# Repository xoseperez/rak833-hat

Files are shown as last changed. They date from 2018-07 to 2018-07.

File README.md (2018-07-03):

# RAK833 Hat for Raspberry Pi

This repository contains the PCB design for a hat and installation procedure to use a RAK833 MiniPCI-E module with a Raspberry Pi.




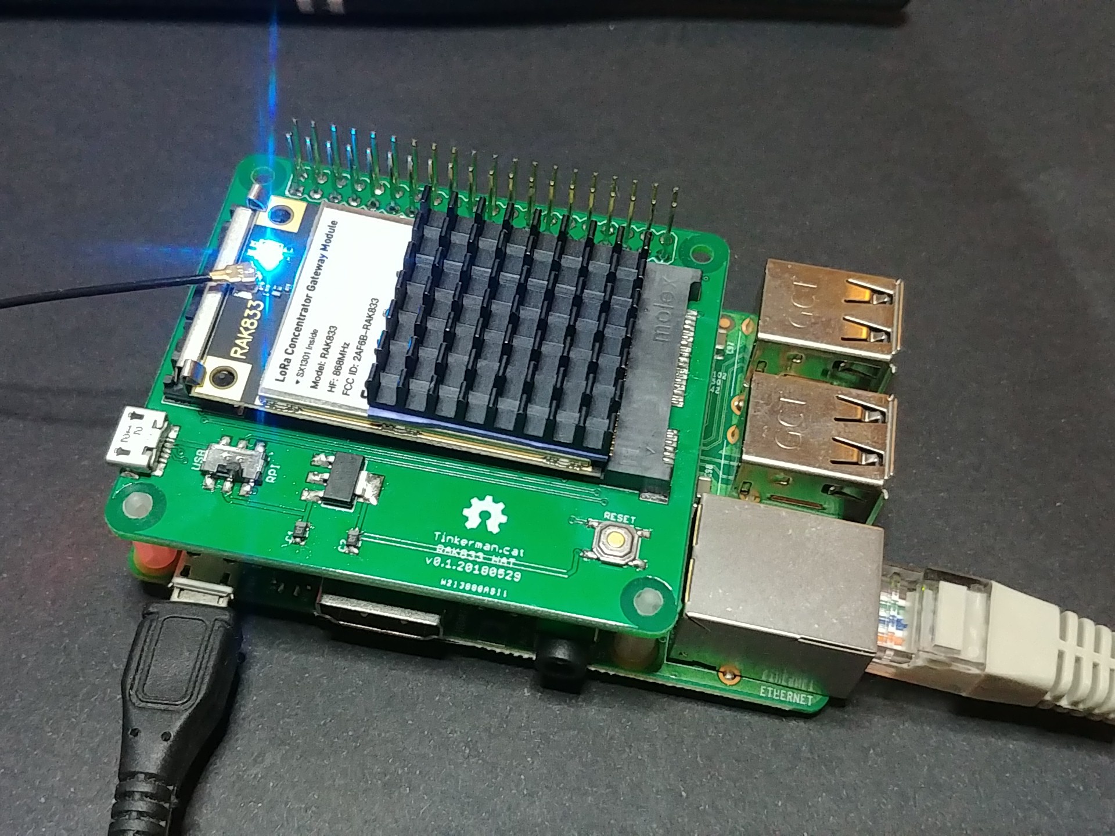
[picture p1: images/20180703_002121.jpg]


## Licenses

The installation procedure is based on the [ttn-zh](http://github.com/ttn-zh) installation procedure for the [IMST iC880a](https://github.com/ttn-zh/ic880a-gateway) module and thus uses the same GPL-3.0 license.

The PCB design and layout is licensed under CC-SA-BY-4.0 International.

License files are available under each folder.

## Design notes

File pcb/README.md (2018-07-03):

# RAK833 Hat

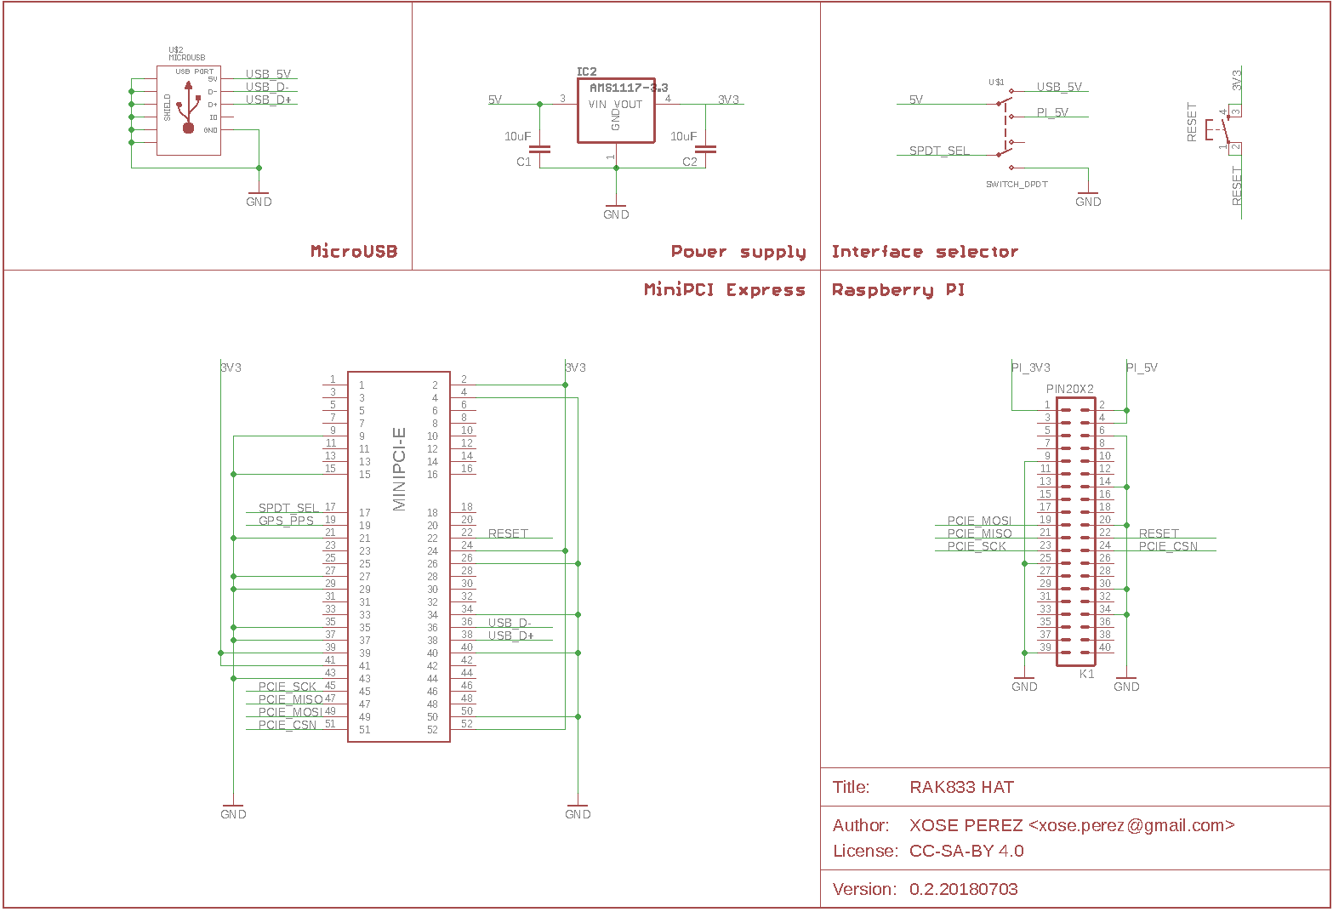
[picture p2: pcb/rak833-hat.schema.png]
Schematic


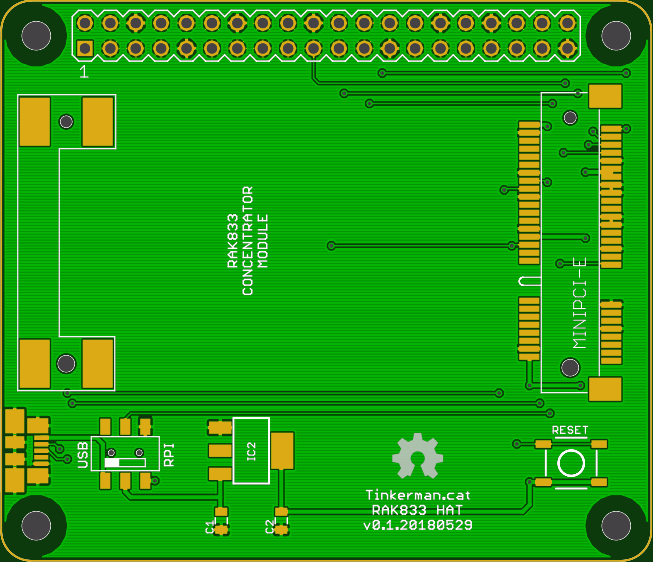
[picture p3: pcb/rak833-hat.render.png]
Render


## Bill of materials

This is the bill of materials for the RAK833 Hat for Raspberry Pi.

You will need an SPI or SPI/USB (more expensive) RAK833 concentrator. RAK Wireless sells them on their Aliexpress store, there is no other place to buy it from IFAIK.

|Item|Qty|Datasheet|Reference|Unit price (*)|
| :--- | :---: | :---: | :---: | :---: |
| RAK833 PCB (lead-free, buying 5 units) | 1 | | [PCBWay](https://www.pcbway.com/project/shareproject/RAK833_Raspberry_Pi_Hat_v0_1_20180529.html) | 3.8€ |
| RAK833 MiniPCI | 1 | [PDF](http://docs.rakwireless.com/en/RAK833%20PCIE%20LoRa%20Gateway/hardware%20design/RAK833%20LoRa%20Gateway%20DataSheet%20V1.3.pdf) | [Aliexpress (SPI-only)](https://www.aliexpress.com/item/RAK833-SPI-SX1301Chip-868-915MHz-Industrial-Grade-Mini-PCIe-LoRa-Gateway-Concentrator-Module-support-SPI-Interface/32887664396.html)<br />[Aliexpress (SPI & USB)](https://www.aliexpress.com/item/RAK833-SPI-USB-Industrial-Grade-Mini-PCIe-LoRa-Gateway-Concentrator-Module-SX1301-FT2232H-Chip-868-915MHz/32867370031.html) | 86.41€<br />103.87€ |
| Glass Fiber Antenna Gain 6dbm | 1 | | [Aliexpress](https://www.aliexpress.com/store/product/Glass-Fiber-Antenna-Gain-6dbm-Transmission-range-is-further-LoRa-Gateway-Antenna-with-433-470-868/2805180_32852314761.html) | 24.02€ |
| Molex MiniPCI-E 4.0H connector | 1 | [PDF](https://www.mouser.es/datasheet/2/276/480996701_sd-155861.pdf) | [Mouser (connector)](https://www.mouser.es/ProductDetail/538-67910-1002) <br /> [Mouser (latch)](https://www.mouser.es/ProductDetail/538-48099-5701) | 1.82€<br />1.07€ |
| Molex 47346-1001 microUSB connector | 1 | [PDF](https://www.mouser.es/datasheet/2/276/0473461001_IO_CONNECTORS-272892.pdf) | [Mouser](https://www.mouser.es/ProductDetail/538-47346-1001) | 0.55€ |
| AMS1117-3V3 | 1 | | [Aliexpress](https://www.aliexpress.com/item/10pcs-AMS1117-3-3-AMS1117-LM1117-1117-3-3V-1A-Voltage-Regulator/32348815272.html) | 0.03€ |
| 10uF 6.3V Tantalum Capacitors | 2 | [PDF](https://www.mouser.es/datasheet/2/40/tps-776850.pdf) | [Mouser](https://www.mouser.es/ProductDetail/581-TPSR106K006R1500) | 0.60€ |
| SMD DPDT switch | 1 | | [Aliexpress](https://www.aliexpress.com/item/5PCS-3-Position-6-Pins-DPDT-Panel-PCB-Mount-Mini-SMD-SMT-Slide-Switch-7x6x4mm/32553945435.html) | 0.69€ |
| SMD push button | 1 | | [Aliexpress](https://www.aliexpress.com/item/100PC-Lot-SMD-4-4-1-5MM-4X4X1-5MM-Tactile-Tact-Push-Button-Micro-Switch-Momentary/32623940621.html) | 0.01€ |
| Raspberry Pi 3 | 1 | | | ~30€ |
| 20x2 2.54pitch header for Raspberry Pi | 1 | | | ~0.25€ |
| **TOTAL (SPI-only version)** | | | | **~150€** |

(*) Prices are shown here for reference. They might change depending on your supplier. They also change depending on the number of units you buy. All prices excluding shipping or customs.

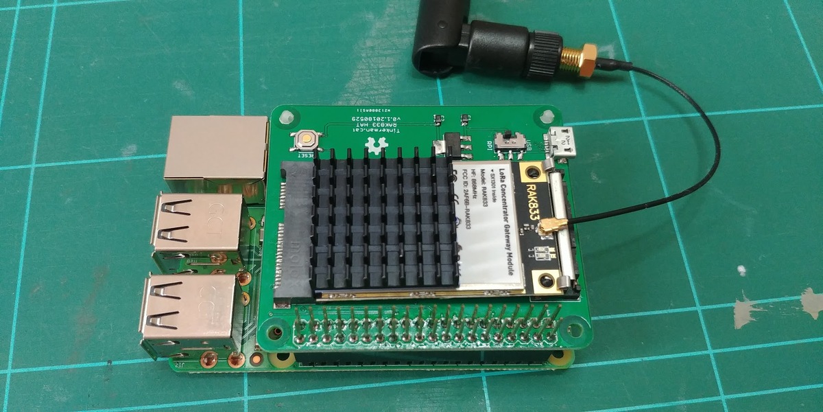
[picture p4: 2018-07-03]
images/small/20180702_132220s.jpg

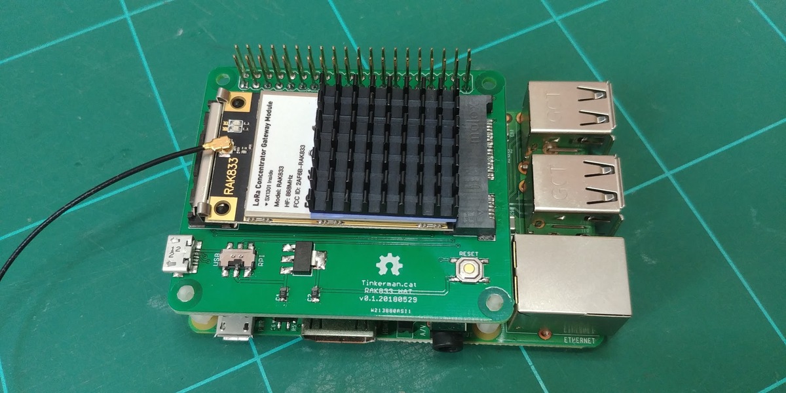
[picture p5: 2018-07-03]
images/small/20180702_132230s.jpg

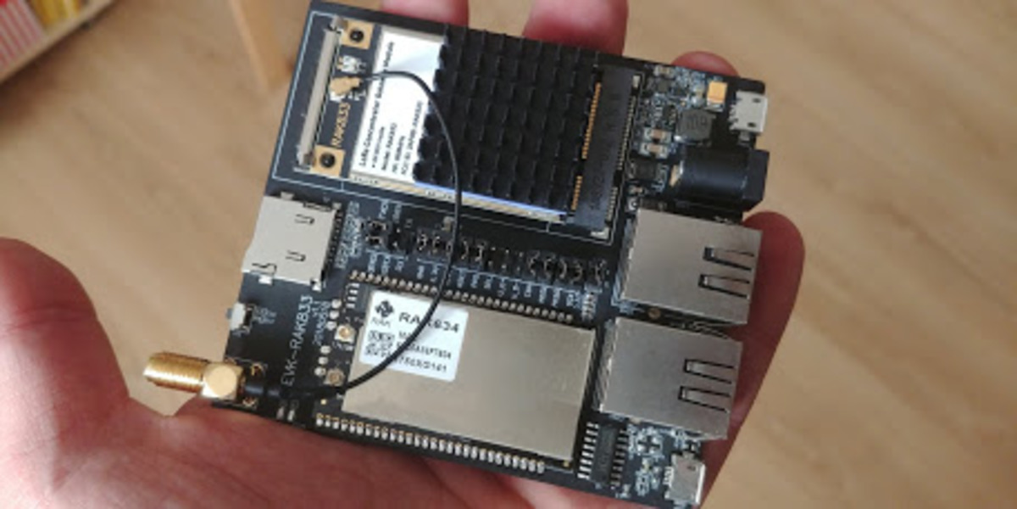
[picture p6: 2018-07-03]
images/small/20180626_130729s.jpg

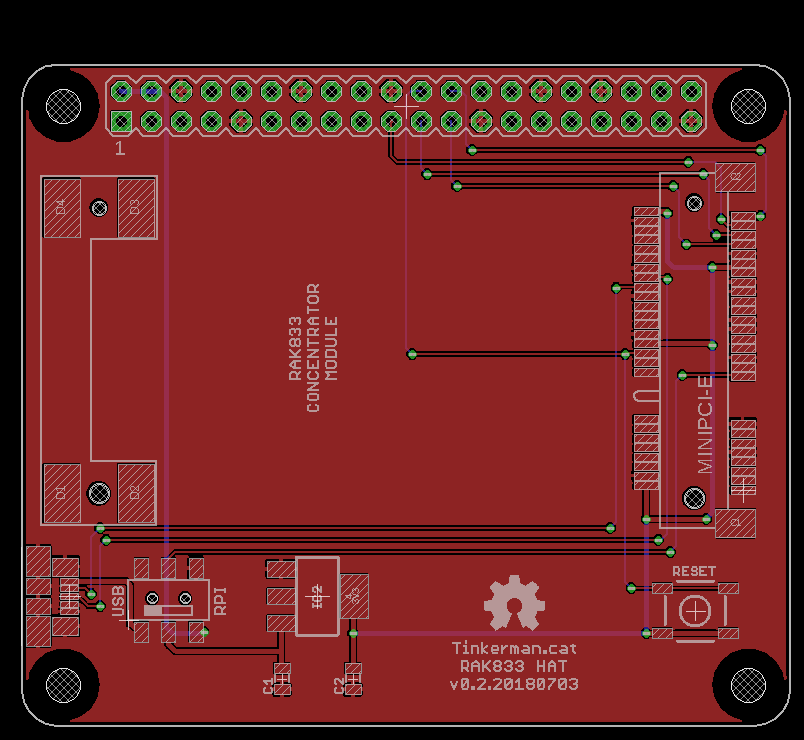
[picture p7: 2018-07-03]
pcb/rak833-hat.layout.png

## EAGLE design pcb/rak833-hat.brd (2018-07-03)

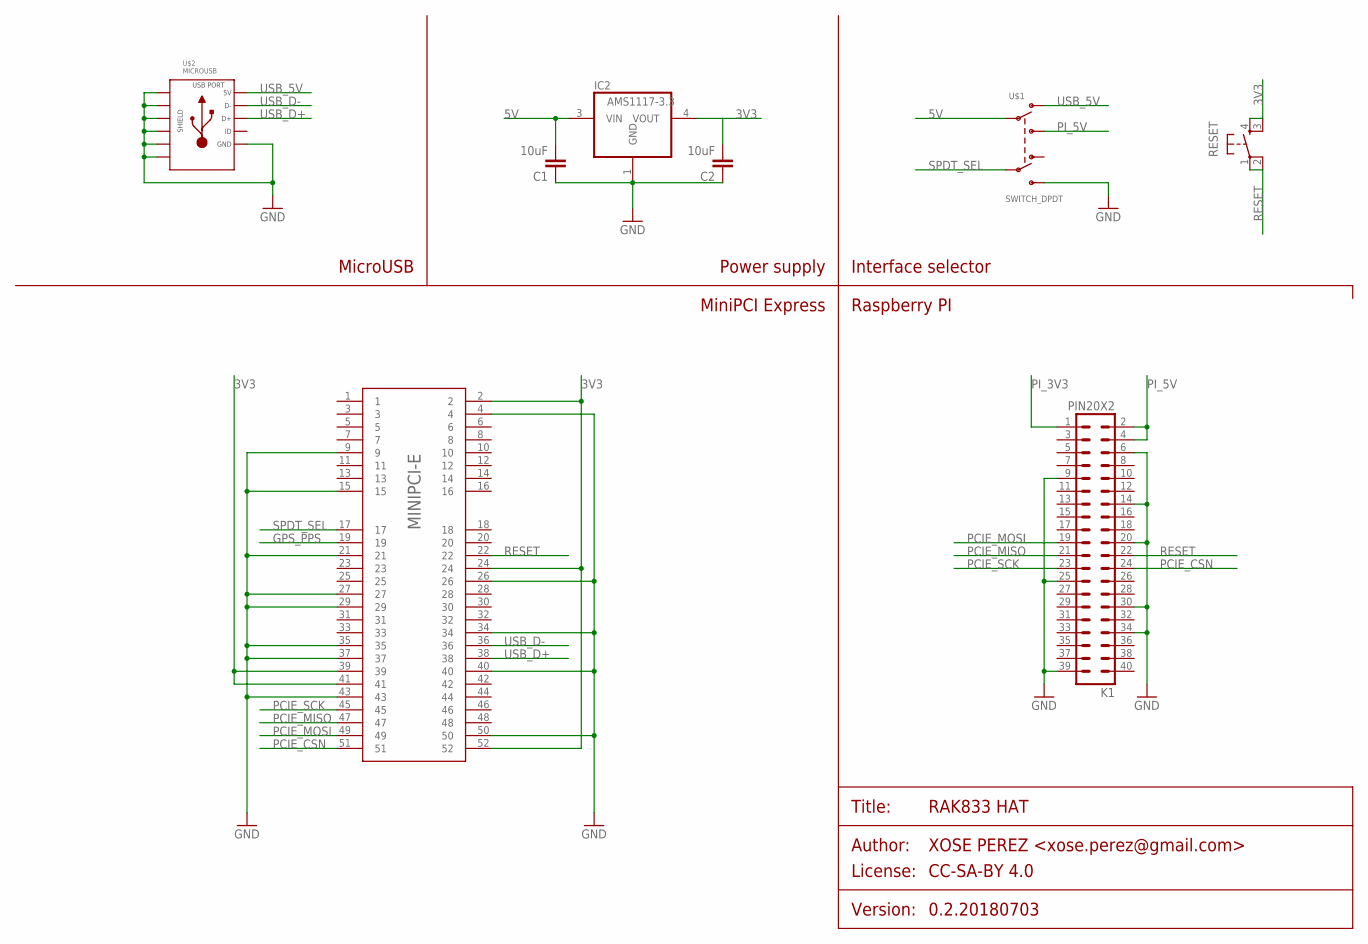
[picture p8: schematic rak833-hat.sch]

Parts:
C1, C2: 10uF; 0805
IC2: AMS1117-3.3; SOT223
K1: PIN20X2; PIN_20X2
MINIPCI-E: MINI-PCIE-RAW; 67910-MINI-PCIE
RESET: TACTILE_BUTTON_SMD; TACTILE-BUTTON-SMD
U$1: SWITCH_DPDT; SWITCH_DPDT_SMD
U$2: MICROUSB; MICROUSB-MOLEX-47346-0001

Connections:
3V3: C2.2, IC2.4 (VOUT), MINIPCI-E.2, MINIPCI-E.24, MINIPCI-E.39, MINIPCI-E.41, MINIPCI-E.52, RESET.3 (SWB2), RESET.4 (SWA2)
5V: C1.2, IC2.3 (VIN), U$1.A1 (P1)
GND: C1.1, C2.1, IC2.1 (GND), K1.6, K1.9, K1.14, K1.20, K1.25, K1.30, K1.34, K1.39, MINIPCI-E.4, MINIPCI-E.9, MINIPCI-E.15, MINIPCI-E.21, MINIPCI-E.26, MINIPCI-E.27, MINIPCI-E.29, MINIPCI-E.34, MINIPCI-E.35, MINIPCI-E.37, MINIPCI-E.40, MINIPCI-E.43, MINIPCI-E.50, U$1.C2 (S2), U$2.GND, U$2.SLD1, U$2.SLD2, U$2.SLD3, U$2.SLD4, U$2.SLD5, U$2.SLD6
GPS_PPS: MINIPCI-E.19
PCIE_CSN: K1.24, MINIPCI-E.51
PCIE_MISO: K1.21, MINIPCI-E.47
PCIE_MOSI: K1.19, MINIPCI-E.49
PCIE_SCK: K1.23, MINIPCI-E.45
PI_3V3: K1.1
PI_5V: K1.2, K1.4, U$1.C1 (S1)
RESET: K1.22, MINIPCI-E.22, RESET.1 (SWA1), RESET.2 (SWB1)
SPDT_SEL: MINIPCI-E.17, U$1.A2 (P2)
USB_5V: U$1.B1 (O1), U$2.VCC (5V)
USB_D+: MINIPCI-E.38, U$2.D+
USB_D-: MINIPCI-E.36, U$2.D-

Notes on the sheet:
MiniPCI Express
Raspberry PI
Interface selector
Power supply
MicroUSB

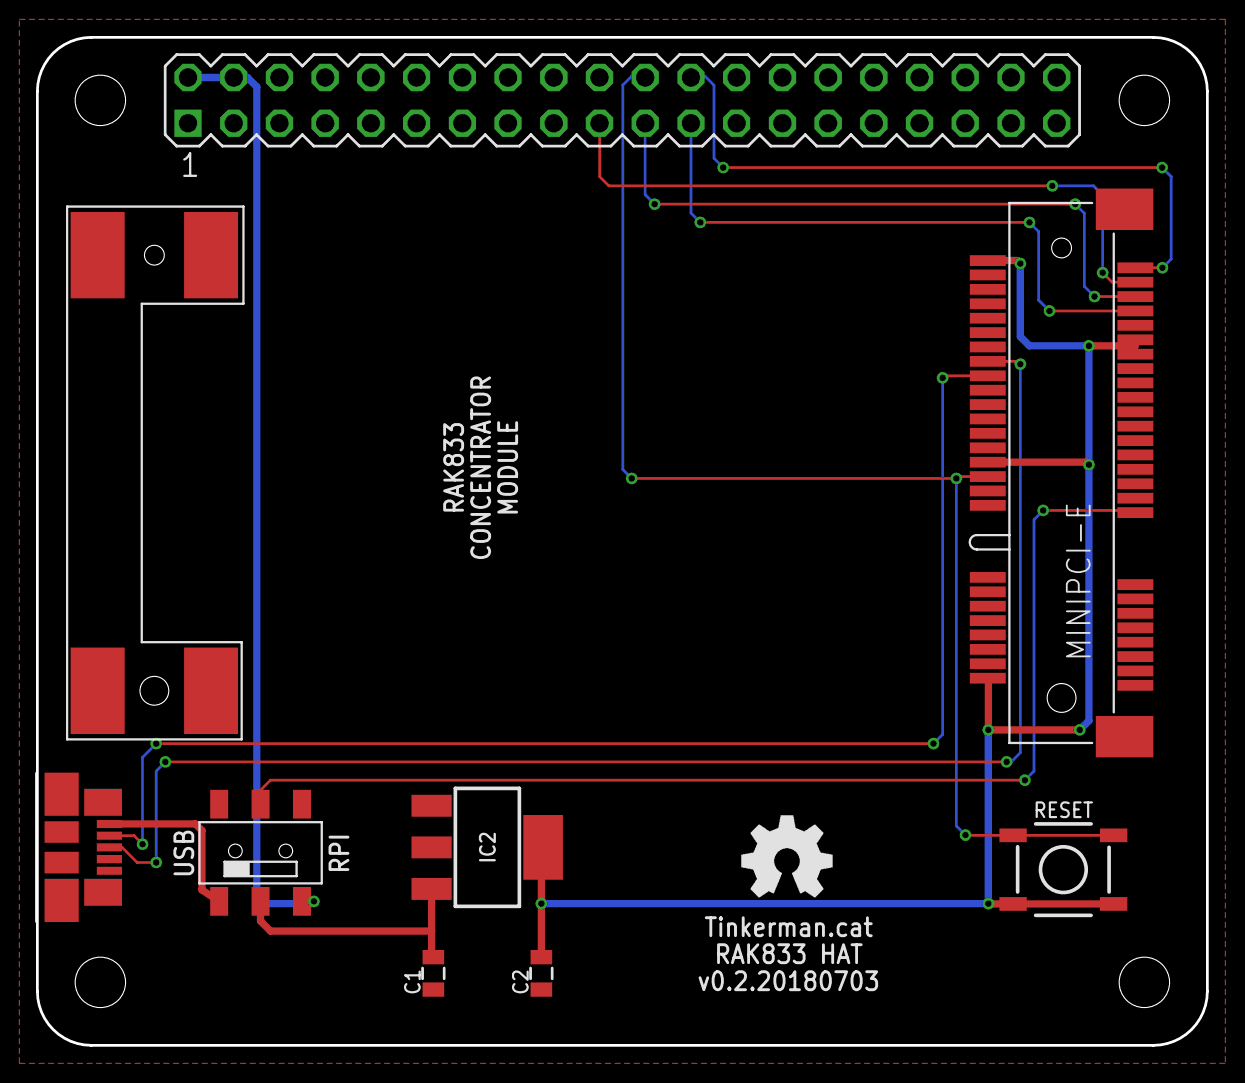
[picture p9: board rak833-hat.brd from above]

Board: 2 copper layers, 65.0 x 56.0 mm, 8 parts (0 on the bottom side), 13 nets.

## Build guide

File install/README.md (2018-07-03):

# The Things Network: RAK833-based gateway

Reference setup for [The Things Network](http://thethingsnetwork.org/) gateways based on the RAK833 USB concentrator with a Raspberry Pi host using the RAK833 hat available in this same repository.

> This documentation and installation procedure is based largely on [gonzalocasas](https://github.com/gonzalocasas) and [ttn-zh](https://github.com/ttn-zh) installation procedure for the [IMST iC880a](https://github.com/ttn-zh/ic880a-gateway) with minor changes to make it compatible with the RAK833-hat for the RAK833 module by RAK Wireless.

## Setup based on Raspbian image

- Download [Raspbian Jessie Lite](https://www.raspberrypi.org/downloads/)
- Follow the [installation instruction](https://www.raspberrypi.org/documentation/installation/installing-images/README.md) to create the SD card
- Plug the RAK833-Hat with the RAK833 module connected
- Start your RPi connected to Ethernet
- From a computer in the same LAN, `ssh` into the RPi using the default hostname:

        local $ ssh pi@raspberrypi.local

- Default password of a plain-vanilla RASPBIAN install for user `pi` is `raspberry`
- Use `raspi-config` utility to configure locale options, expand the filesystem and enable SSH and SPI interfaces:

        $ sudo raspi-config

- Reboot
- Make sure you have an updated installation and install `git`:

        $ sudo apt-get update
        $ sudo apt-get upgrade
        $ sudo apt-get install git

- Create new user for TTN and add it to sudoers

        $ sudo adduser ttn
        $ sudo adduser ttn sudo

- Logout and login as `ttn` and remove the default `pi` user

        $ sudo userdel -rf pi

- Ethernet connection is recommended, if you still want to use WiFi configure the WiFi credentials (check [here for additional details](https://www.raspberrypi.org/documentation/configuration/wireless/wireless-cli.md))

        $ sudo nano /etc/wpa_supplicant/wpa_supplicant.conf

        network={
            ssid="The_SSID_of_your_wifi"
            psk="Your_wifi_password"
        }

- Clone [the installer](https://github.com/ttn-zh/RAK833-gateway/) and start the installation

        $ git clone https://github.com/xoseperez/rak833-hat.git
        $ cd ~/rak833-hat/install
        $ sudo ./install.sh

- If you want to use the remote configuration option, please make sure you have created a JSON file named as your gateway EUI (e.g. `B827EBFFFE7B80CD.json`) in the [Gateway Remote Config repository](https://github.com/ttn-zh/gateway-remote-config).
- **Big Success!** You should now have a running gateway in front of you!

# Credits

Credits for [gonzalocasas](https://github.com/gonzalocasas) and [ttn-zh](https://github.com/ttn-zh) for their installation procedure for the IMST iC880a. Also, that procedure is largely based on the awesome work by [Ruud Vlaming](https://github.com/devlaam) on the [Lorank8 installer](https://github.com/Ideetron/Lorank).

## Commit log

2018-07-02 PCB version 0.1.20180529
    [rak833-hat.brd, rak833-hat.sch]
2018-07-03 Fixing switch footprint
    [rak833-hat.brd, rak833-hat.sch]
2018-07-03 Images and BOM

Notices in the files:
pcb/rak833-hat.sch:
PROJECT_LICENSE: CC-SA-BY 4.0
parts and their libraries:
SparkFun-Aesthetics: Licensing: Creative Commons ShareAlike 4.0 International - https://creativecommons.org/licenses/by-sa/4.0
